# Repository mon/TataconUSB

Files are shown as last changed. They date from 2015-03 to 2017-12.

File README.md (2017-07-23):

# TataconUSB
A small dongle to connect your Wii taiko controller to your computer as a USB
device, instead of using Bluetooth.

[Purchase here](https://mon.im/tatacon/)  
[User guide](UserGuide.md)

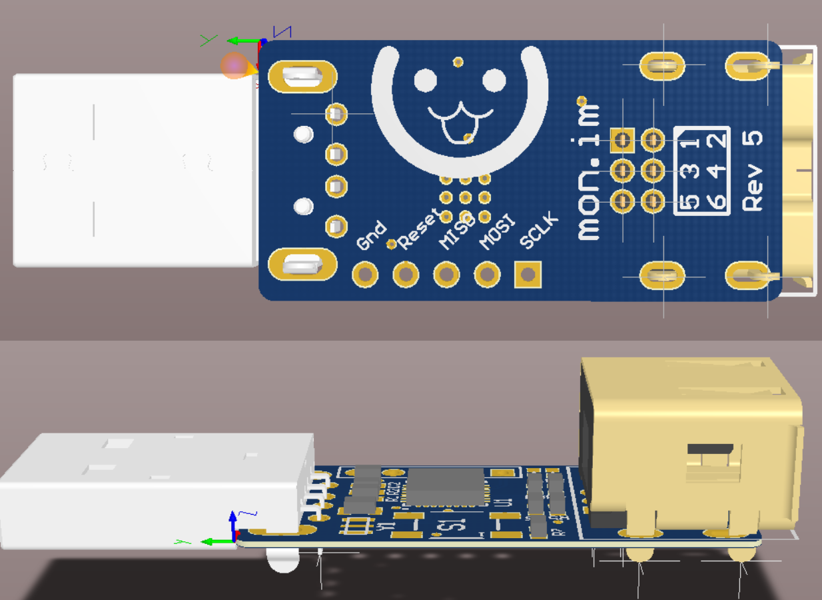
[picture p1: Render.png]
Tatacon


## Features
- Uses an atmega16u2 and the LUFA USB stack
- 1ms response time.
- Sweet LEDs (can be turned off)
- Responds so fast you can bounce your sticks and get multi hits. Can be turned off with Debounce feature.
- Tested working on official, Hori and knockoff controllers
- Windows, Linux, Mac compatible + [cross platform Chrome app for configuration](https://chrome.google.com/webstore/detail/tataconfig/ndeibflmpllogilncdmoajadcopjkchg)
- Config app allows future firmware updates to add more features
- No drivers required!

## Building firmware:
At console, run `make`. You will need AVR GCC installed.

## Building software:
It's a Chrome web app. Install it like a normal dev app.

## Building hardware:
Send v5 Gerbers to a PCB fab and have fun with QFN soldering. If you want
a little less fiddling, use the seeed_bom.csv file along with the Gerbers
and use Seedstudio's Fusion PCBA service. Use a board thickness of 8mm.
As Seeed doesn't have them, you will need to add a USB A Male connector
(any through hole model should fit) and a Raphnet Nunchuck connector.

Altium Designer was used, open TataconUSB.PrjPcb as the main file.

Program the HID bootloader and clock fuses via `make init` and an SPI programmer.
The makefile is by default setup to use the USBAsp. I recommend pogo pins
in a breadboard + USB connection for power.
From there, program by hitting the hardware reset button, then `make flash`.

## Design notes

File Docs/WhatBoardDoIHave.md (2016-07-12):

# Which board do I have?

### You have a V5 if...
- Your converter came with a case
- Your converter has a half smiley face on the bottom
- Your converter has `Rev 5` written on the bottom.
- Your reset switch is on the left

### You have a V4 if...
- Your converter did not come with a case
- Your converter has an entire smiley face on the bottom
- Your reset switch is on the lower section

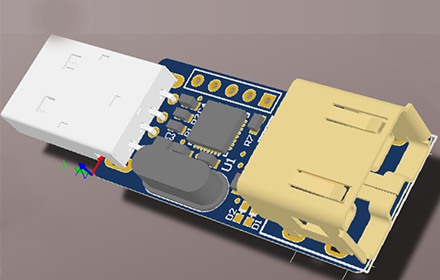
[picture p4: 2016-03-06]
Software/Tataconfig/Promotional.png

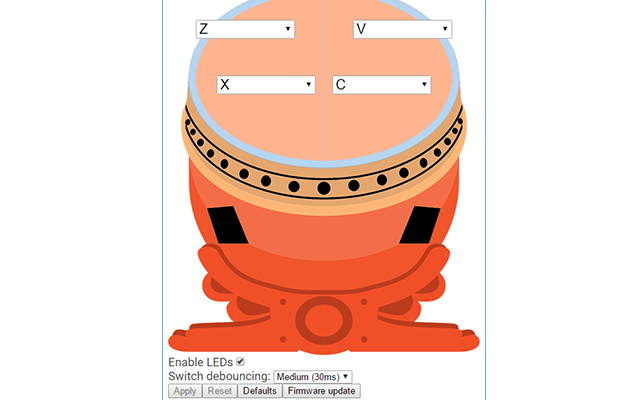
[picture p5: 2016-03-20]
Software/Tataconfig/Screenshot.png

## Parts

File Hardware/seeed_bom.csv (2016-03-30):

Part/Designator | OPL SKU | Quantity
C1 | 302010178 | 1 | USB filter cap
C2 | 302010139 | 1 | filter cap
D1 | 304090042 | 1 | red LED
D2 | 304090045 | 1 | blue LED
R1,R2 | 301010289 | 2 | USB resistors
R3,R4 | 301010163 | 2 | LED resistors
R5,R6 | 301010113 | 2 | i2c pullup
R7 | 301010299 | 1 | reset pullup
S1 | 311020017 | 1 | reset switch
U1 | 310010018 | 1 | atmega
Y1 | 306030005 | 1 | resonator

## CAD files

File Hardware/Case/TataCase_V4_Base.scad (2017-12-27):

include <TataconCaseBase.scad>

pcb_length = 37.3;
switch_offsetx = 4.85;
switch_offsety = 22.1 + usb_ramp_length;

// ver 4 clip must come further because of crystal leeway
usb_clip_strength = 0.8;
// ver 4 nub is too far forward
usb_nub_strength = 0;
usb_relative_z = 0;

board_clearance_top = 3.3 + fudge; // height of crystal

led_x = board_width+wall_strength;
led_y = 21.4 + usb_ramp_length;

crystal_bottom = 18.3;

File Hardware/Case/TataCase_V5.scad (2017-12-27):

include <TataconCaseBase.scad>

rotate([90,0,0])
board();

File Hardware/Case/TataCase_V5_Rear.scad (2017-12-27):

include <TataconCaseBase.scad>

rear_clip();

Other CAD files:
Hardware/Case/TataCase_V5_Thin.scad
Hardware/Case/BezierScad.scad
Hardware/Case/TataCase_V4.scad
Hardware/Case/TataCase_V4_Rear.scad
Hardware/Case/TataCase_V5_Thin_Base.scad
Hardware/Case/TataCase_V5_Thin_Rear.scad
Hardware/Case/TataconCase.scad
Hardware/Case/TataconCaseBase.scad

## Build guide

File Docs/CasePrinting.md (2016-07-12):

First, [work out which board](WhatBoardDoIHave.md) you have.

Go to [the Thingiverse entry](http://www.thingiverse.com/thing:1656531) for the cases and download the correct version
for the board you have.

You now have several options:
- Print it yourself
- Take your STL and send it to someone from 3DHubs.

Regardless of what you choose, make sure to follow the print settings listed
on the Thingiverse listing.

Most importantly, ensure that you print the cases in the orientation that they've
been rendered at - small side down for the case, and clip side down for the rear
cover.

My cases are printed in PLA but ABS should work fine.

## Installing the PCB
Simply slide the PCB into the open back of the case. Depending on your tolerances,
this may be a tight fit. Don't panic! It's designed to be locked in so it doesn't
come out when inserting it into the USB port.
**Make sure the reset switch doesn't get caught on the rear opening.** The
switch itself is quite fragile and will easily pop off if you are too violent.

Once the board is snapped in, insert the rear cover. It's designed to bend, so
expect a nice snug fit. **If you are using V4** this won't be quite flush with the
back of the case. This is due to a PCB design oversight when I made the V4 board.

*If you have any issues with a self-printed case, please don't hesitate to contact me!*

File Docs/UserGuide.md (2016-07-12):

# Overview
There are several ports on the converters:
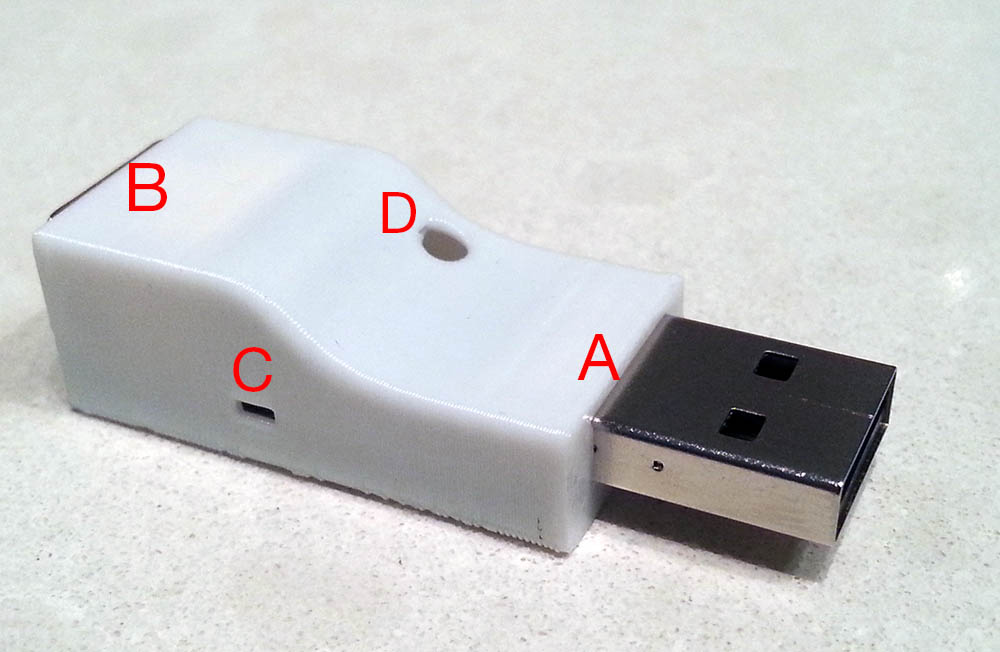
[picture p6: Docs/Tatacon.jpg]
Tatacon overview


* A - USB port. Plug into computer
* B - Nunchuck port. Plug into Tatacon
* C - Light hole. A hole for blinking
* D - Reset hole. In case of firmware update failure, poking this with a 
toothpick or similar puts the board into failsafe (bootloader) mode.

# Configuration
Plug the converter in to your computer and open the [TaTaConfig](https://chrome.google.com/webstore/detail/tataconfig/ndeibflmpllogilncdmoajadcopjkchg).
Here are the available settings:

* Keys - The converter pretends to be a keyboard. Which keys should it hit?
* Enable LEDs - Enable or disable LEDs on each hit
* Switch debouncing. If 2 hits are made within the debounce time, the second
is ignored. Higher values give less false positives. Lower values let you bounce
your sticks for drum rolls.

# Programming
**At the time of writing, there are no firmware updates** for the converters.

However, if you would like to write or fork your own firmware, you are free to.
You can program via USB using the HIDBootloader sample application from the
LUFA distribution. If you want to modify the bootloader, you must use the ISP
breakouts. Plug the converter into a USB port for power, and connect the rest
of the pins to the labelled pads on the board.

I used pogo pins and a short USB extension lead when programming the boards,
and it made the process very fast.

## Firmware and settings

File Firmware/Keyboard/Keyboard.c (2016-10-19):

#include "Keyboard.h"
#include "i2cmaster.h"
#include "Config.h"

#ifdef DEBUG
#include "usbio.h"
#include <util/delay.h>
#endif

#define LED_DIR  DDRD
#define LED_PORT PORTD
#define DON_LED_PIN  6
#define KAT_LED_PIN  5

// V1 has no LEDs
#ifdef V1_BUILD
    #define SET(port, pin)
    #define CLEAR(port, pin)
    #define TOGGLE(port, pin)
#else
    #define SET(port, pin) port |= _BV(pin)
    #define CLEAR(port, pin) port &= ~_BV(pin)
    #define TOGGLE(port, pin) port ^= _BV(pin)
#endif

/** Buffer to hold the previously generated Keyboard HID report, for comparison purposes inside the HID class driver. */
static uint8_t PrevKeyboardHIDReportBuffer[sizeof(USB_KeyboardReport_Data_t)];
static uint8_t PrevGenericHIDReportBuffer[TATACON_CONFIG_BYTES];

/** LUFA HID Class driver interface configuration and state information. This structure is
 *  passed to all HID Class driver functions, so that multiple instances of the same class
 *  within a device can be differentiated from one another.
 */
USB_ClassInfo_HID_Device_t Keyboard_HID_Interface =
{
    .Config =
        {
            .InterfaceNumber              = INTERFACE_ID_Keyboard,
            .ReportINEndpoint             =
                {
                    .Address              = KEYBOARD_EPADDR,
                    .Size                 = KEYBOARD_EPSIZE,
                    .Banks                = 1,
                },
            .PrevReportINBuffer           = PrevKeyboardHIDReportBuffer,
            .PrevReportINBufferSize       = sizeof(PrevKeyboardHIDReportBuffer),
        },
};

USB_ClassInfo_HID_Device_t Generic_HID_Interface =
{
    .Config =
        {
            .InterfaceNumber              = INTERFACE_ID_Generic,
            .ReportINEndpoint             =
                {
                    .Address              = GENERIC_EPADDR,
                    .Size                 = GENERIC_EPSIZE,
                    .Banks                = 1,
                },
            .PrevReportINBuffer           = PrevGenericHIDReportBuffer,
            .PrevReportINBufferSize       = sizeof(PrevGenericHIDReportBuffer),
        },
};
    
typedef struct {
    // optimise data sending
    uint8_t state;
    uint8_t lastReport;
    uint8_t debounce;
} switch_t;

static switch_t switches[KB_SWITCHES];
static uint8_t switchesChanged = 1;
static uint8_t nunchuckReady = 0;

#ifdef DEBUG
#define DEBUG_DELAY_MS 10
static uint8_t debugDelay = 100; // don't do anything for 100ms
#endif

uint32_t Boot_Key ATTR_NO_INIT;
#define MAGIC_BOOT_KEY            0xDEADBE7A
// offset * word size
#define BOOTLOADER_START_ADDRESS  (0x1c00 * 2)

void Bootloader_Jump_Check(void) ATTR_INIT_SECTION(3);
void Bootloader_Jump_Check(void)
{
    // If the reset source was the bootloader and the key is correct, clear it and jump to the bootloader
    if ((MCUSR & (1 << WDRF)) && (Boot_Key == MAGIC_BOOT_KEY))
    {
        Boot_Key = 0;
        ((void (*)(void))BOOTLOADER_START_ADDRESS)();
    }
}

//todo: neater
#define NUNCHUCK_ADDR (0x52 << 1)
void Nunchuck_back(void) {
    if(!nunchuckReady) {
        nunchuckReady = 1;
        // Turn LEDs off, it returned
        CLEAR(LED_PORT, DON_LED_PIN);
        CLEAR(LED_PORT, KAT_LED_PIN);
    }
}

void Nunchuck_gone(void) {
    i2c_stop();
    if(nunchuckReady) {
        nunchuckReady = 0;
        // Turn LEDs on until it returns
        SET(LED_PORT, DON_LED_PIN);
        SET(LED_PORT, KAT_LED_PIN);
        // Clear structs
        for(int i = 0; i < KB_SWITCHES; i++) {
            switches[i].state = 0;
            if(switches[i].state != switches[i].lastReport) {
                switchesChanged = 1;
            }
        }
    }
}

void Nunchuck_Init(void) {
    // try to say hello
    if(!i2c_start(NUNCHUCK_ADDR | I2C_WRITE)) {
        i2c_write(0xF0);
        i2c_write(0x55);
        i2c_stop();
        _delay_ms(25);
        
        i2c_start(NUNCHUCK_ADDR | I2C_WRITE);
        i2c_write(0xFB);
        i2c_write(0x00);
        i2c_stop();
        _delay_ms(25);
        Nunchuck_back();
    } else {
        Nunchuck_gone();
    }
}

uint8_t Nunchuck_ReadByte(uint8_t address) {
    uint8_t data = 0xFF;
    
    if(!nunchuckReady) {
        Nunchuck_Init();
    }

    if(!i2c_start(NUNCHUCK_ADDR | I2C_WRITE)) {
        i2c_write(address);
        i2c_stop();

        i2c_start(NUNCHUCK_ADDR | I2C_READ);
        data = i2c_readNak();
        i2c_stop();
        Nunchuck_back();
    } else {
        Nunchuck_gone();
    }
    return data;
}

// Starting at address, read n bytes and return the last
void Nunchuck_ReadMany(uint8_t address, uint8_t *data, uint8_t count) {
    
    if(!nunchuckReady) {
        Nunchuck_Init();
    }

    if(!i2c_start(NUNCHUCK_ADDR | I2C_WRITE)) {
        i2c_write(address);
        i2c_stop();

        i2c_start(NUNCHUCK_ADDR | I2C_READ);
        for(uint8_t i = 0; i < count-1; i++) {
            data[i] = i2c_readAck();
        }
        data[count-1] = i2c_readNak();
        i2c_stop();
        Nunchuck_back();
    } else {
        Nunchuck_gone();
    }
}

void update_switches(void) {
    uint8_t data, i;
    
    // Data for the buttons is at this address
    data = Nunchuck_ReadByte(0x05);

    // Not using KB_SWITCHES, because of Tatacon limits
    for(i = 0; i < 4; i++) {
        // The I2C data starts at the 6th bit and goes down
        uint8_t newState = !(data & _BV(6-i));
        if(!switches[i].debounce && newState != switches[i].lastReport) {
            switches[i].state = newState;
            switches[i].debounce = tataConfig.debounce;
            switchesChanged = 1;
        }
    }
}

/** Main program entry point. This routine contains the overall program flow, including initial
 *  setup of all components and the main program loop.
 */
int main(void)
{
    uint8_t i;
    // Clear structs
    for(i = 0; i < KB_SWITCHES; i++) {
        switches[i].state = 0;
        switches[i].lastReport = 0;
        switches[i].debounce = 0;
    }
    
    InitConfig();
    
	SetupHardware();

	GlobalInterruptEnable();
    
#ifdef DEBUG
    printf_P(PSTR("Tatacon to USB Debug Mode\n\n"));
    uint8_t tmp[6];
    Nunchuck_ReadMany(0xFA, tmp, 6);
    if(nunchuckReady) {
        // ID debug
        printf_P(PSTR("Tatacon found with ID:\n"));
        for(uint8_t i = 0; i < 6; i++) {
            if(tmp[i] < 0x10) {
                printf("0");
            }
            printf("%X ", tmp[i]);
        }
        printf("\n\n");
        // Register debug
        Nunchuck_ReadMany(0x00, tmp, 6);
        printf_P(PSTR("Dumping registers 0x00 to 0x05:\n"));
        for(uint8_t i = 0; i < 6; i++) {
            if(tmp[i] < 0x10) {
                printf("0");
            }
            printf("%X ", tmp[i]);
        }
        printf("\n\n");
    } else {
        printf_P(PSTR("Tatacon not found or not responding\n\n"));
    }
    // Switch debug
    printf_P(PSTR("Key order: DL, KL, CR, KR\n"));
#endif

	for (;;)
	{
		HID_Device_USBTask(&Keyboard_HID_Interface);
		HID_Device_USBTask(&Generic_HID_Interface);
		USB_USBTask();
	}
}

void SetupHardware()
{
	/* Disable watchdog if enabled by bootloader/fuses */
	MCUSR &= ~(1 << WDRF);
	wdt_disable();
    
#ifdef V1_BUILD
    CLKPR = (1 << CLKPCE); // enable a change to CLKPR
	CLKPR = 0; // set the CLKDIV to 0 - was 0011b = div by 8 taking 8MHz to 1MHz
#endif

	/* Hardware Initialization */
    SET(LED_DIR, DON_LED_PIN);
    SET(LED_DIR, KAT_LED_PIN);
#ifdef DEBUG
    init_usb_stdio();
    SET(LED_PORT, DON_LED_PIN);
    for(int i = 0; i < 32; i++) {
        TOGGLE(LED_PORT, DON_LED_PIN);
        TOGGLE(LED_PORT, KAT_LED_PIN);
        _delay_ms(125);
    }
#endif
    if(tataConfig.ledsOn) {
        // Turn them on until we init with the nunchuck
        SET(LED_PORT, DON_LED_PIN);
        SET(LED_PORT, KAT_LED_PIN);
    }
    i2c_init();
    Nunchuck_Init();
	USB_Init();
}

/** HID class driver callback function for the creation of HID reports to the host.
 *
 *  \param[in]     HIDInterfaceInfo  Pointer to the HID class interface configuration structure being referenced
 *  \param[in,out] ReportID    Report ID requested by the host if non-zero, otherwise callback should set to the generated report ID
 *  \param[in]     ReportType  Type of the report to create, either HID_REPORT_ITEM_In or HID_REPORT_ITEM_Feature
 *  \param[out]    ReportData  Pointer to a buffer where the created report should be stored
 *  \param[out]    ReportSize  Number of bytes written in the report (or zero if no report is to be sent)
 *
 *  \return Boolean \c true to force the sending of the report, \c false to let the library determine if it needs to be sent
 */
bool CALLBACK_HID_Device_CreateHIDReport(USB_ClassInfo_HID_Device_t* const HIDInterfaceInfo,
                                         uint8_t* const ReportID,
                                         const uint8_t ReportType,
                                         void* ReportData,
                                         uint16_t* const ReportSize)
{
    if(ReportType != HID_REPORT_ITEM_In) {
        *ReportSize = 0;
        return false;
    }
    if (HIDInterfaceInfo == &Keyboard_HID_Interface) {
        USB_KeyboardReport_Data_t* KeyboardReport = (USB_KeyboardReport_Data_t*)ReportData;
#ifdef DEBUG
        memset(KeyboardReport, 0, sizeof(USB_KeyboardReport_Data_t));
        update_switches();
        if(switchesChanged) {
            for(uint8_t i = 0; i < KB_SWITCHES; i++) {
                printf("%d ", switches[i].state);
                switches[i].lastReport = switches[i].state;
            }
            printf("\n");
            switchesChanged = 0;
        }
        if(!debugDelay) {
            uint8_t wroteData = make_report(KeyboardReport);
            if(wroteData) {
                debugDelay = DEBUG_DELAY_MS;
                *ReportSize = sizeof(USB_KeyboardReport_Data_t);
                return true;
            } else {
                *ReportSize = 0;
                return false;
            }
        }
#else
        update_switches();
        
        if(!switchesChanged) {
            *ReportSize = 0;
            return false;
        }
        
        CLEAR(LED_PORT, DON_LED_PIN);
        CLEAR(LED_PORT, KAT_LED_PIN);
         
        for(uint8_t i = 0; i < KB_SWITCHES; i++) {
            KeyboardReport->KeyCode[i] = switches[i].state ? tataConfig.switches[i] : 0;
            switches[i].lastReport = switches[i].state;
            // Update blinkenlights
            if(switches[i].state) {
                if(tataConfig.ledsOn) {
                    if(i % 2) { // odd indexes are kat, even don
                        SET(LED_PORT, KAT_LED_PIN);
                    } else {
                        SET(LED_PORT, DON_LED_PIN);
                    }
                }
            }
        }
         
        *ReportSize = sizeof(USB_KeyboardReport_Data_t);
         
        switchesChanged = 0;
        return true;
#endif
    } else if(HIDInterfaceInfo == &Generic_HID_Interface) {
        uint8_t* ConfigReport = (uint8_t*)ReportData;
        memcpy(ConfigReport, &tataConfig, sizeof(tatacon_config_t));
        *ReportSize = TATACON_CONFIG_BYTES;
        //TOGGLE(LED_PORT, DON_LED_PIN);
        return true;
    }
    *ReportSize = 0;
    return false;

}

/** HID class driver callback function for the processing of HID reports from the host.
 *
 *  \param[in] HIDInterfaceInfo  Pointer to the HID class interface configuration structure being referenced
 *  \param[in] ReportID    Report ID of the received report from the host
 *  \param[in] ReportType  The type of report that the host has sent, either HID_REPORT_ITEM_Out or HID_REPORT_ITEM_Feature
 *  \param[in] ReportData  Pointer to a buffer where the received report has been stored
 *  \param[in] ReportSize  Size in bytes of the received HID report
 */
void CALLBACK_HID_Device_ProcessHIDReport(USB_ClassInfo_HID_Device_t* const HIDInterfaceInfo,
                                          const uint8_t ReportID,
                                          const uint8_t ReportType,
                                          const void* ReportData,
                                          const uint16_t ReportSize)
{
    if(HIDInterfaceInfo == &Generic_HID_Interface && ReportType == HID_REPORT_ITEM_Out) {
        uint8_t* ConfigReport = (uint8_t*)ReportData;
        // So we can upgrade firmware without having to hit the button
        if(ConfigReport[TATACON_CONFIG_BYTES-1] == MAGIC_RESET_NUMBER) {
            // With this uncommented, reboot fails. Odd.
            //USB_Disable();
            cli();

            // Back to the bootloader
            Boot_Key = MAGIC_BOOT_KEY;
            wdt_enable(WDTO_250MS);
            while(1);
        }
        SetConfig(ConfigReport);
    }
}


/** Event handler for the library USB Connection event. */
void EVENT_USB_Device_Connect(void)
{
	
}

/** Event handler for the library USB Disconnection event. */
void EVENT_USB_Device_Disconnect(void)
{
    
}

/** Event handler for the library USB Configuration Changed event. */
void EVENT_USB_Device_ConfigurationChanged(void)
{
	HID_Device_ConfigureEndpoints(&Keyboard_HID_Interface);
	HID_Device_ConfigureEndpoints(&Generic_HID_Interface);

	USB_Device_EnableSOFEvents();
}

/** Event handler for the library USB Control Request reception event. */
void EVENT_USB_Device_ControlRequest(void)
{
	HID_Device_ProcessControlRequest(&Keyboard_HID_Interface);
	HID_Device_ProcessControlRequest(&Generic_HID_Interface);
}

/** Event handler for the USB device Start Of Frame event. */
void EVENT_USB_Device_StartOfFrame(void)
{
	HID_Device_MillisecondElapsed(&Keyboard_HID_Interface);
	HID_Device_MillisecondElapsed(&Generic_HID_Interface);
    
    for(int i = 0; i < KB_SWITCHES; i++) {
        if(switches[i].debounce) {
            switches[i].debounce--;
        }
    }
#ifdef DEBUG
    if(debugDelay) {
        debugDelay--;
    }
#endif
}

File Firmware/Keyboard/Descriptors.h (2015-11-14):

/*
             LUFA Library
     Copyright (C) Dean Camera, 2014.

  dean [at] fourwalledcubicle [dot] com
           www.lufa-lib.org
*/

/*
  Copyright 2014  Dean Camera (dean [at] fourwalledcubicle [dot] com)

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
  The author disclaims all warranties with regard to this
  software, including all implied warranties of merchantability
  and fitness.  In no event shall the author be liable for any
  special, indirect or consequential damages or any damages
  whatsoever resulting from loss of use, data or profits, whether
  in an action of contract, negligence or other tortious action,
  arising out of or in connection with the use or performance of
  this software.
*/

/** \file
 *
 *  Header file for Descriptors.c.
 */

#ifndef _DESCRIPTORS_H_
#define _DESCRIPTORS_H_

	/* Includes: */
		#include <avr/pgmspace.h>

		#include <LUFA/Drivers/USB/USB.h>
        
        #include "Config.h"

	/* Type Defines: */
		/** Type define for the device configuration descriptor structure. This must be defined in the
		 *  application code, as the configuration descriptor contains several sub-descriptors which
		 *  vary between devices, and which describe the device's usage to the host.
		 */
		typedef struct
		{
			USB_Descriptor_Configuration_Header_t Config;

			// Keyboard HID Interface
			USB_Descriptor_Interface_t            HID1_Interface;
			USB_HID_Descriptor_HID_t              HID1_KeyboardHID;
			USB_Descriptor_Endpoint_t             HID1_ReportINEndpoint;
            
            // Generic HID Interface
			USB_Descriptor_Interface_t            HID2_Interface;
			USB_HID_Descriptor_HID_t              HID2_VendorHID;
			USB_Descriptor_Endpoint_t             HID2_ReportINEndpoint;
		} USB_Descriptor_Configuration_t;

		/** Enum for the device interface descriptor IDs within the device. Each interface descriptor
		 *  should have a unique ID index associated with it, which can be used to refer to the
		 *  interface from other descriptors.
		 */
		enum InterfaceDescriptors_t
		{
			INTERFACE_ID_Keyboard = 0, /**< Keyboard interface descriptor ID */
            INTERFACE_ID_Generic =  1  /**< Generic interface descriptor ID  */
		};

		/** Enum for the device string descriptor IDs within the device. Each string descriptor should
		 *  have a unique ID index associated with it, which can be used to refer to the string from
		 *  other descriptors.
		 */
		enum StringDescriptors_t
		{
			STRING_ID_Language     = 0, /**< Supported Languages string descriptor ID (must be zero) */
			STRING_ID_Manufacturer = 1, /**< Manufacturer string ID */
			STRING_ID_Product      = 2, /**< Product string ID */
			STRING_ID_Config       = 3, /**< Config string ID */
			STRING_ID_Tatacon      = 4, /**< Config string ID */
		};

	/* Macros: */
		/** Endpoint address of the Keyboard HID reporting IN endpoint. */
		#define KEYBOARD_EPADDR              (ENDPOINT_DIR_IN | 1)
        
        #define GENERIC_EPADDR               (ENDPOINT_DIR_IN | 2)

		/** Size in bytes of the Keyboard HID reporting IN endpoint. */
		#define KEYBOARD_EPSIZE              8
		#define GENERIC_EPSIZE               TATACON_CONFIG_BYTES

	/* Function Prototypes: */
		uint16_t CALLBACK_USB_GetDescriptor(const uint16_t wValue,
		                                    const uint8_t wIndex,
		                                    const void** const DescriptorAddress)
		                                    ATTR_WARN_UNUSED_RESULT ATTR_NON_NULL_PTR_ARG(3);

#endif

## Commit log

2014-11-14 Add pretty render + 3D models for all parts
    [Parts.PcbLib, TataconUSB.PcbDoc]
2014-11-14 More realistic board thickness in 3D view
    [TataconUSB.PcbDoc]
2014-11-14 Silkscreen art
    [TataconUSB.PcbDoc]
2014-11-14 Correct Gerber generation
    [TataconUSB.PcbDoc, TataconUSB.PrjPcb]
2014-11-14 Add zip of Gerbers for V1
2014-11-25 Change MCU to atmega8u2, due to V-USB being nonstandard
    [Parts.PcbLib, TataconUSB.PcbDoc, TataconUSB.PrjPcb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]
2014-11-29 Fix PCB layout for SMD parts with pads - should be top layer only, not multilayer. Fixes reverse side tenting.
    [Parts.PcbLib, TataconUSB.PcbDoc, TataconUSB.SchDoc]
2014-12-05 Fix nunchuck shape, crystal for a tighter fit
    [Parts.PcbLib, TataconUSB.PcbDoc, TataconUSB.PrjPcb]
2014-12-05 Enlarge the data pins on nunchuck as they were a bit small
    [Parts.PcbLib, TataconUSB.PcbDoc]
2014-12-05 Reorganise project outputs, add gerbers for V1 and V2
2015-03-20 Half finished revised hardware - add pushbutton, LEDs etc
    [Parts.PcbLib, TataconUSB.PcbDoc, TataconUSB.PrjPcb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]
2015-09-21 Version 3!
    [TataconUSB.PcbDoc, TataconUSB.SchDoc]
2015-11-13 Update gitignore and hardware
    [TataconUSB.PrjPcb, TataconUSB.SchDoc]
2015-11-13 Make device appear as keyboard in device manager
2015-11-13 Fixed clock rates - 1.2ms latency instead of 20ms
    [Keyboard.c]
2015-11-13 Revert "Make device appear as keyboard in device manager"
    This reverts commit afccdbe05a91583465834dfe005f4f8415e4958f.
2015-11-13 We're not actually self powered
2015-11-18 Makefile target for V1 board, add debouncing
2015-12-27 Add debug mode for diagnosing controller issues
    [Keyboard.c]
2015-12-27 I2C - 400KHz mode, wait for slave on clock, fixes Hori and other 3rd party controllers
    [Keyboard.c]
2015-12-30 Software reset, version num in config, and minor code cleanups
    [Keyboard.c]
2015-12-30 Update defaults, fix no LED mode
    [Keyboard.c]
2015-12-31 Hardware V4!
    Add pullup resistors
    Add ground pin on programming header
    Add labels for programming header
    Change to 8MHz crystal for valid 3.3V operation
    [TataconUSB.PcbDoc, TataconUSB.PrjPcb, TataconUSB.SchDoc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]
2016-03-06 Update web app, bootloader, add 3D printed case
    [BezierScad.scad, TataconCase.scad]
2016-03-09 Nunchuck now hangs more to accommodate case
    [TataconCase.scad, TataconUSB.PcbDoc]
2016-03-20 Update app assets and add button to reset to firmware
2016-03-30 Bigger pads on the USB so I can use connectors that aren't $2 each
    [TataconUSB.PcbDoc]
2016-03-30 v4.1 gerbers
2016-03-30 Seeed no longer provides 8MHz DIP crystals. Move to resonator and rev5
    [TataconUSB.PcbDoc, TataconUSB.SchDoc, seeed_bom.csv]
2016-06-30 Many case improvements, vertical print
    [TataconCase.scad]
2016-07-03 Finalise case
    [TataconCase.scad]
2016-07-03 Commit STL files
    [TataconCase_RearCover_forV4.stl, TataconCase_RearCover_forV5.stl, TataconCase_forV4.stl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]
2016-07-12 Add single layer guide for better case fit, increase switch clearance
    [TataconCase.scad, TataconCase_RearCover_forV5.stl, TataconCase_forV5.stl]
2016-07-13 Improved USB ramp
    [TataconCase.scad]
2016-07-18 Case optimisations and improvements
    [TataconCase.scad]
2016-10-19 Better fitting case
    [TataconCase.scad]
2016-10-19 Remove extraneous comments
    Of note - this removes a few copyright notices. I believe my source code is now sufficiently different from the original samples that this is appropriate.
2017-12-27 Long overdue case cleanups
    [TataCase_V4.scad, TataCase_V4_Base.scad, TataCase_V4_Rear.scad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]
2018-09-26 Minor adjustments
    [TataconCaseBase.scad]
